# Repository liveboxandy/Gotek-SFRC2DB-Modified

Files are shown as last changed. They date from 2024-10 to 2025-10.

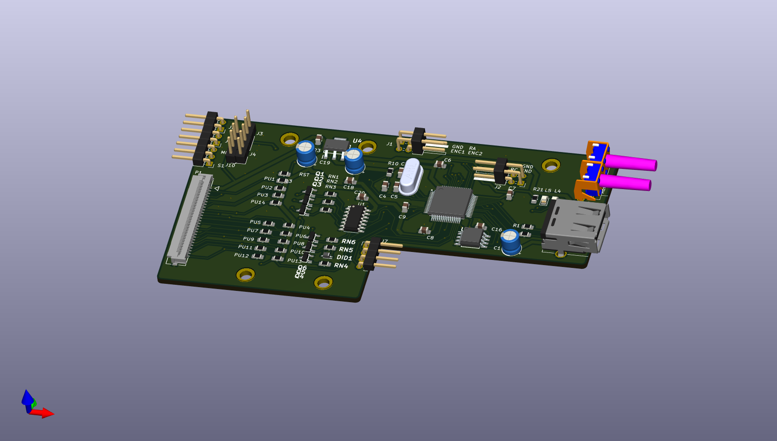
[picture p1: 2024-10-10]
Gotek.png

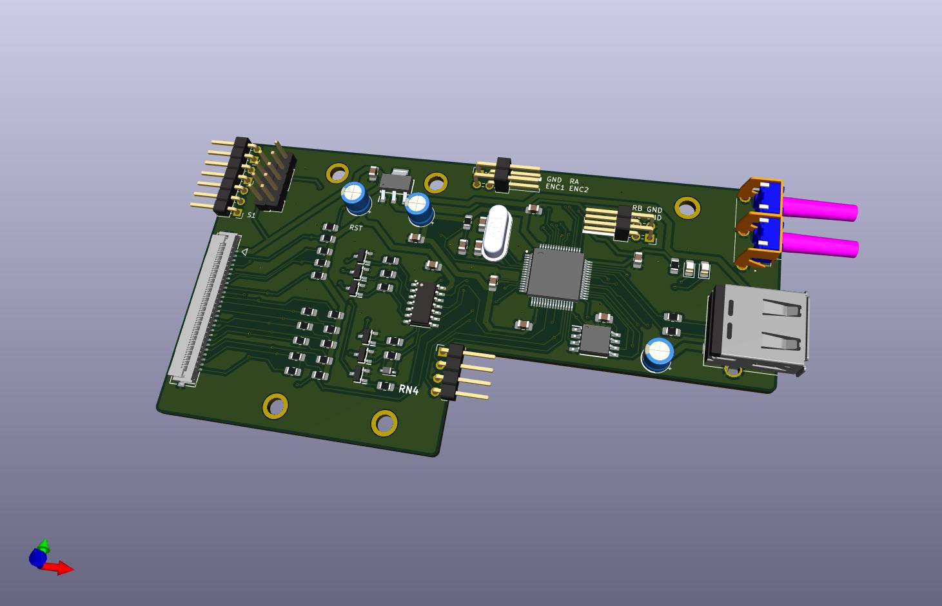
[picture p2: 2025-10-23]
Gotek.jpg

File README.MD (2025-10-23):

Initial schematic and gerbers for a Gotek SFRC2D.B based on an Artery St32F415 chip.
Used photographs and a multimeter without removing any chips. Only removed RA/RB/RC to verify connections to U3.
Should work for the STM105 variant as some of the smoothing caps don't make sense for the Artery chip but do for the STM.
Added connections for a rotary encoder (J1) using U3 Pins 50 (PC10), 51 (PC11) and 37 (PC6) and replaced RB and RC with
a 2x2 RA pin header (J2).

Updated for Kicad 9
Added ibom (bom/ibom.html)
Restructered Folders

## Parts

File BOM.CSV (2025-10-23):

Reference | Value | Datasheet | Footprint | Qty | DNP
C1,C17,C19 | 10uF | ~ | Capacitor_THT:CP_Radial_D5.0mm_P2.50mm | 3
C3,C5 | 22pF | ~ | Capacitor_SMD:C_0805_2012Metric_Pad1.18x1.45mm_HandSolder | 2
C4,C6,C7,C8,C9,C16,C18,C20,C23 | 100nF | ~ | Capacitor_SMD:C_0805_2012Metric_Pad1.18x1.45mm_HandSolder | 9
DID1 | 1N4148WS | https://www.vishay.com/docs/85751/1n4148ws.pdf | Gotek:SODFL2512X90N | 1
J1,J2 | Conn_02x02_Odd_Even | ~ | Connector_PinHeader_2.54mm:PinHeader_2x02_P2.54mm_Horizontal | 2
J3,MO1 | Conn_01x03_Pin | ~ | Connector_PinHeader_2.54mm:PinHeader_1x03_P2.54mm_Horizontal,Connector_PinHeader_2.54mm:PinHeader_1x03_P2.54mm_Vertical | 2
J4,JD1,JE1 | Conn_01x02_Pin | ~ | Connector_PinHeader_2.54mm:PinHeader_1x02_P2.54mm_Horizontal,Connector_PinHeader_2.54mm:PinHeader_1x02_P2.54mm_Vertical | 3
J7 | Display Port | ~ | Connector_PinHeader_2.54mm:PinHeader_1x04_P2.54mm_Horizontal | 1
J10 | Conn_01x04_Pin | ~ | Connector_PinHeader_2.54mm:PinHeader_1x04_P2.54mm_Vertical | 1
L4 | LED GREEN | ~ | LED_SMD:LED_0805_2012Metric_Pad1.15x1.40mm_HandSolder | 1
L5 | LED RED | ~ | LED_SMD:LED_0805_2012Metric_Pad1.15x1.40mm_HandSolder | 1
P1 | Conn_01x26 | 2005280260 | Gotek:MOLEX_CON_2005280260 | 1
P3 | USB_A | ~ | Connector_USB:USB_A_Molex_67643_Horizontal | 1
PU1,PU2,PU3,PU4,PU5,PU6,PU7,PU8,PU9,PU10,PU11,PU12,PU13,PU14,R21,RN1,RN2,RN3,RN4,RN5,RN6 | 1K | ~ | Resistor_SMD:R_0805_2012Metric_Pad1.20x1.40mm_HandSolder | 21
Q1,Q2,Q3,Q4,Q5,Q6 | PMBT2222A,215 | https://assets.nexperia.com/documents/data-sheet/PMBT2222A.pdf | Gotek:SOT95P280X130-3N | 6
R1,R2 | 22R | ~ | Resistor_SMD:R_0805_2012Metric_Pad1.20x1.40mm_HandSolder | 2
R10,RN13 | 4K7 | ~ | Resistor_SMD:R_0805_2012Metric_Pad1.20x1.40mm_HandSolder | 2
S3,S4 | SKHHANA010 | https://www.mouser.co.uk/datasheet/2/15/SKHH-1370651.pdf | Gotek:SKHHLQA010 | 2
U1 | 74AHC04 | https://assets.nexperia.com/documents/data-sheet/74AHC_AHCT04.pdf | Package_SO:SO-14_3.9x8.65mm_P1.27mm | 1
U3 | at32f415rbt7 | https://www.arterytek.com/download/DS/DS_AT32F415_V2.01_CH.pdf | Gotek:QFP50P1200X1200X160-64N | 1
U4 | AMS1117-3.3 | http://www.advanced-monolithic.com/pdf/ds1117.pdf | Gotek:SOT229P700X180-4N | 1
U8 | SST25VF016B-50-4C-S2AF | https://ww1.microchip.com/downloads/en/DeviceDoc/20005044C.pdf | Gotek:SOIC127P790X216-8N | 1
Y1 | 8Mhz | ~ | Crystal:Crystal_HC18-U_Vertical | 1

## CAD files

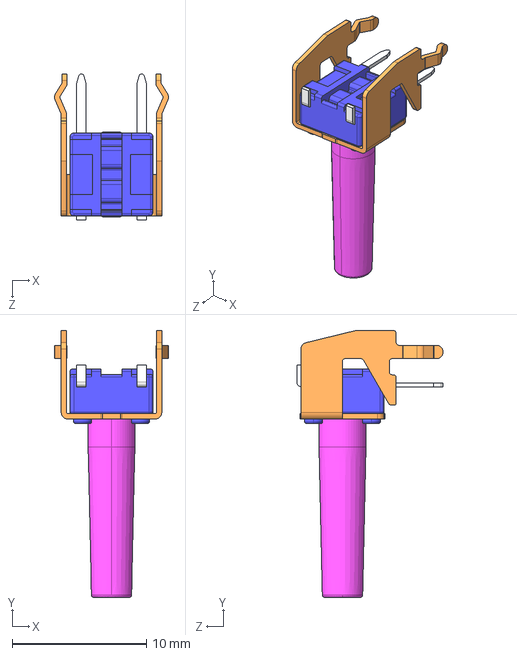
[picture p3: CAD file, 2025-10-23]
STP/SKHHNH.stp
8.50 x 19.9 x 10.9 mm

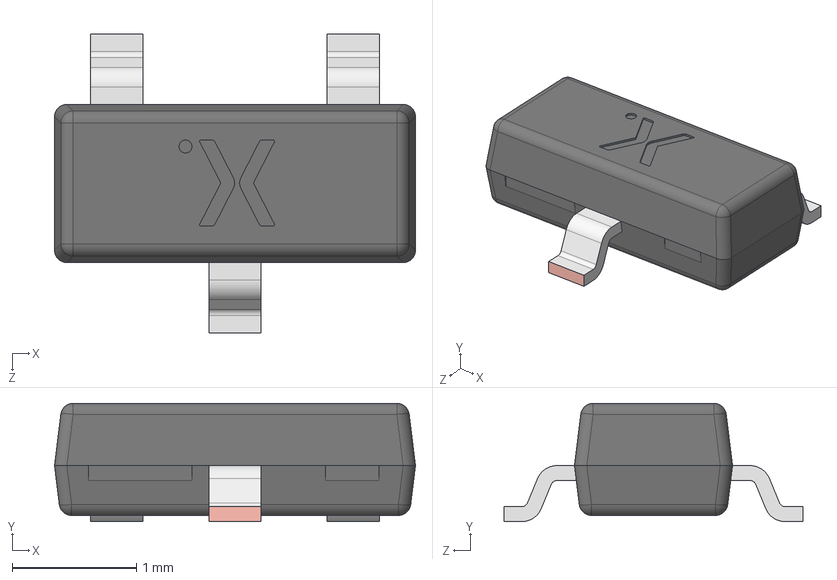
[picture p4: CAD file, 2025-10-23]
STP/PMBT2222A,215.stp
2.90 x 0.95 x 2.40 mm
SOT23 lower body
SOT23 Lead x 3
SOT23 Upper body

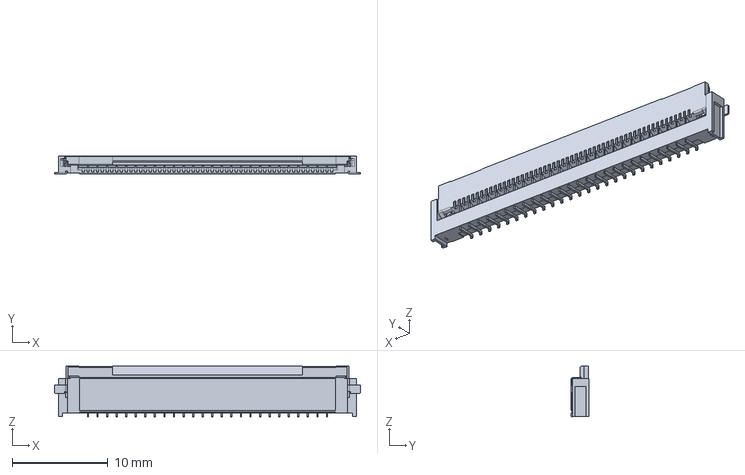
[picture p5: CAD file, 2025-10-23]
STP/Molex 2005280260.stp
32.0 x 1.90 x 5.30 mm

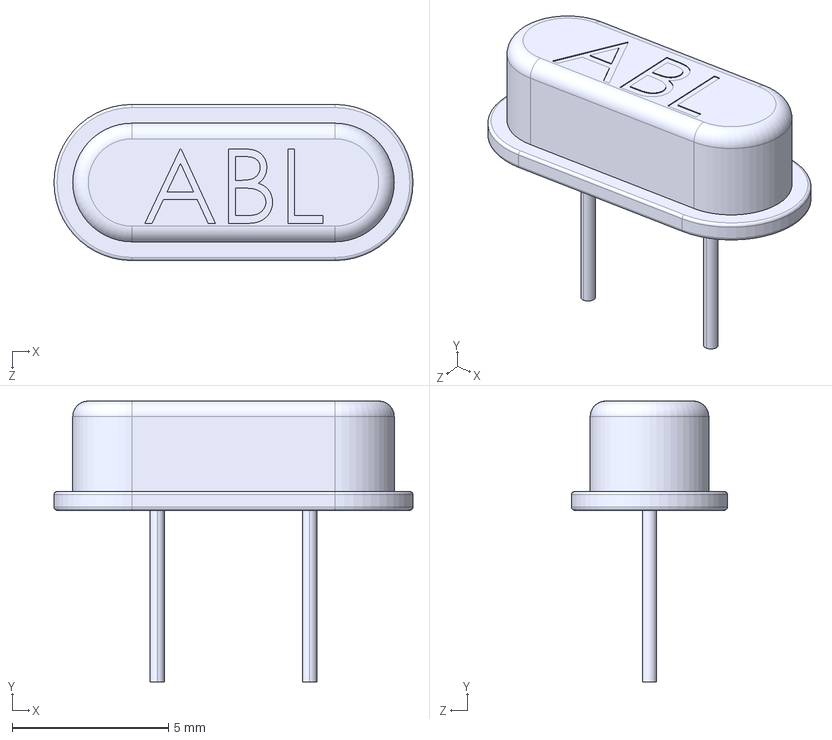
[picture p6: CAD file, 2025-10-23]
STP/ABL-8.000MHZ-B2.stp
11.5 x 9.00 x 5.00 mm

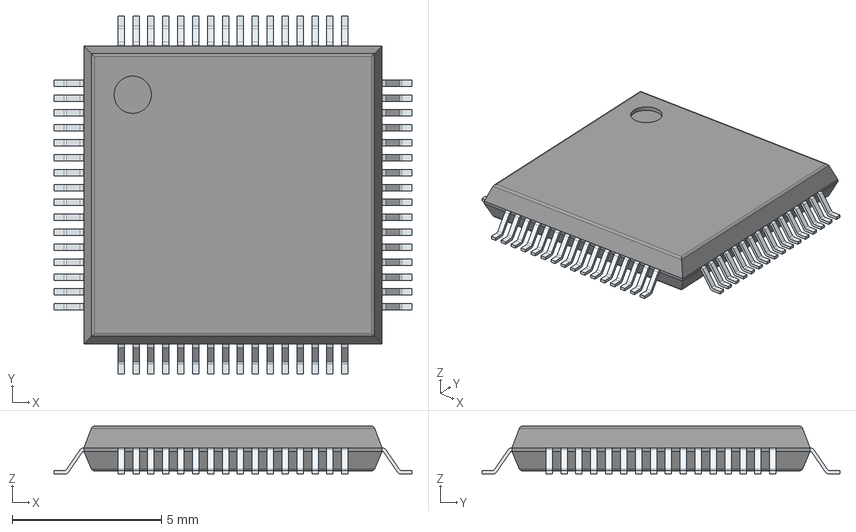
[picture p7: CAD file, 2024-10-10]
STP/AT32F415RxT7.stp
12.0 x 12.0 x 1.60 mm
PinsArrayLR
PinsArrayTB

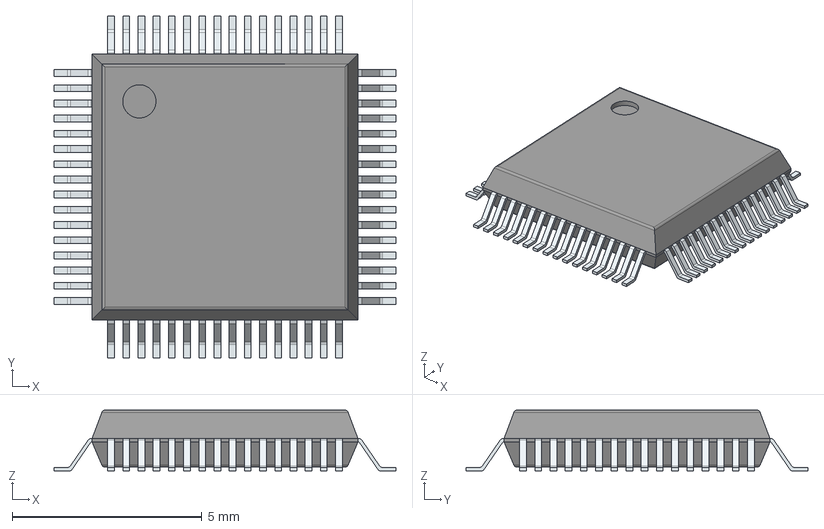
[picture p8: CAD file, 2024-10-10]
STP/at32f415rct7.stp
9.00 x 9.00 x 1.60 mm
PinsArrayLR
PinsArrayTB

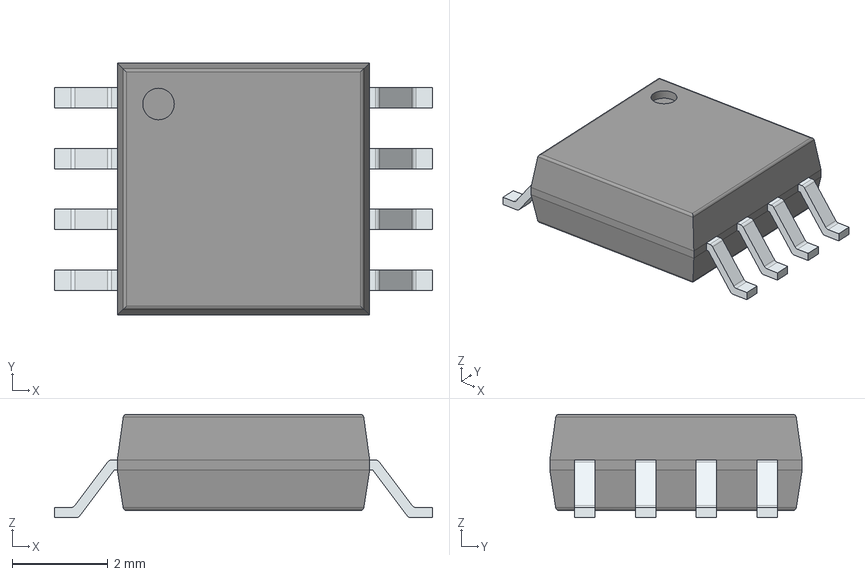
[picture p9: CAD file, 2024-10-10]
STP/SST25VF016B-50-4C-S2AF.stp
7.90 x 5.28 x 2.16 mm
PinsArrayLR

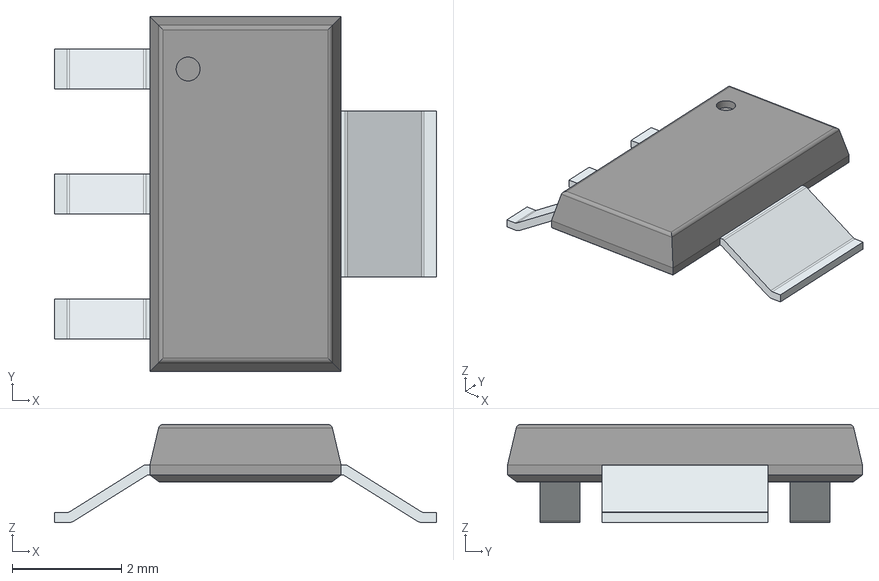
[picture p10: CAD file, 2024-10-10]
STP/ams1117-3.3v.stp
7.00 x 6.50 x 1.80 mm
PinsArrayL
FilletPinR

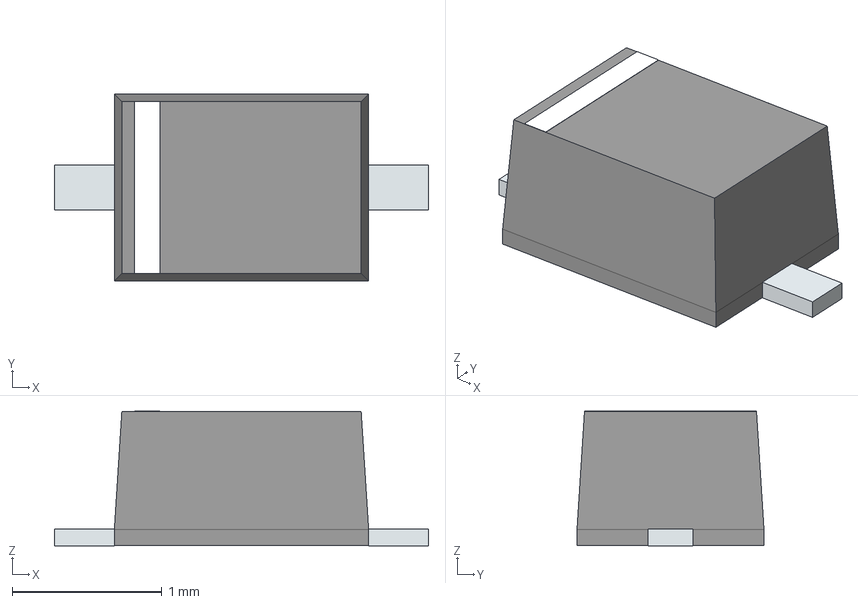
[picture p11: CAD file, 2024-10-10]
STP/1N4148WS.stp
2.50 x 1.25 x 0.9 mm
PinKIdent
PinK
PinA

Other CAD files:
STP/SKHHNK.STEP
STP/SKHHNHA010.stp
STP/SKHHNK.stp

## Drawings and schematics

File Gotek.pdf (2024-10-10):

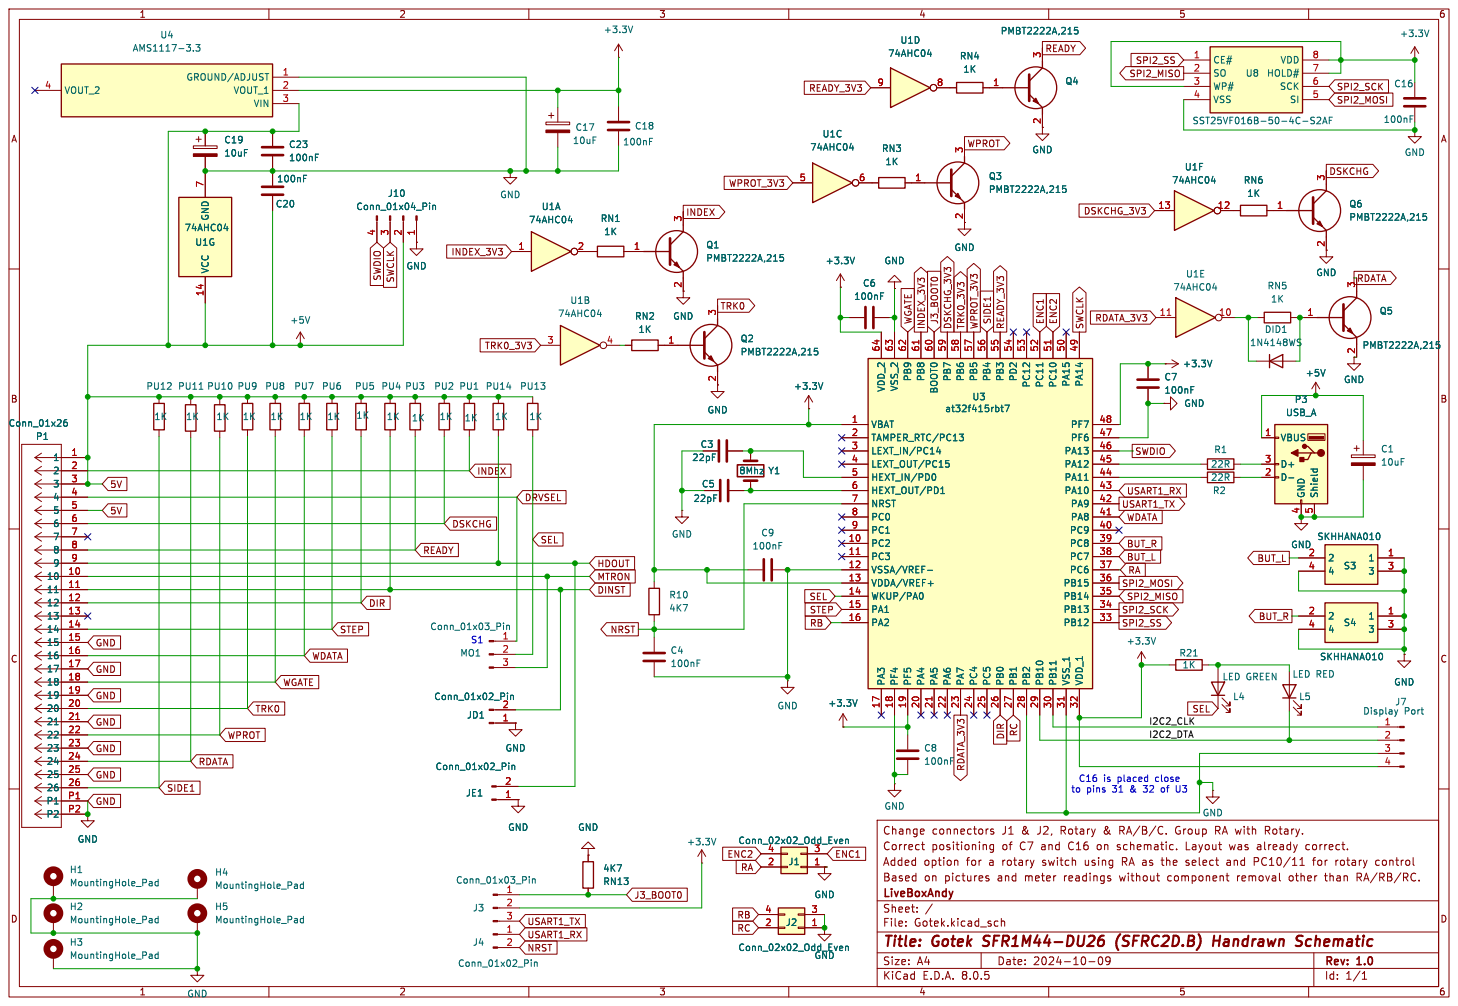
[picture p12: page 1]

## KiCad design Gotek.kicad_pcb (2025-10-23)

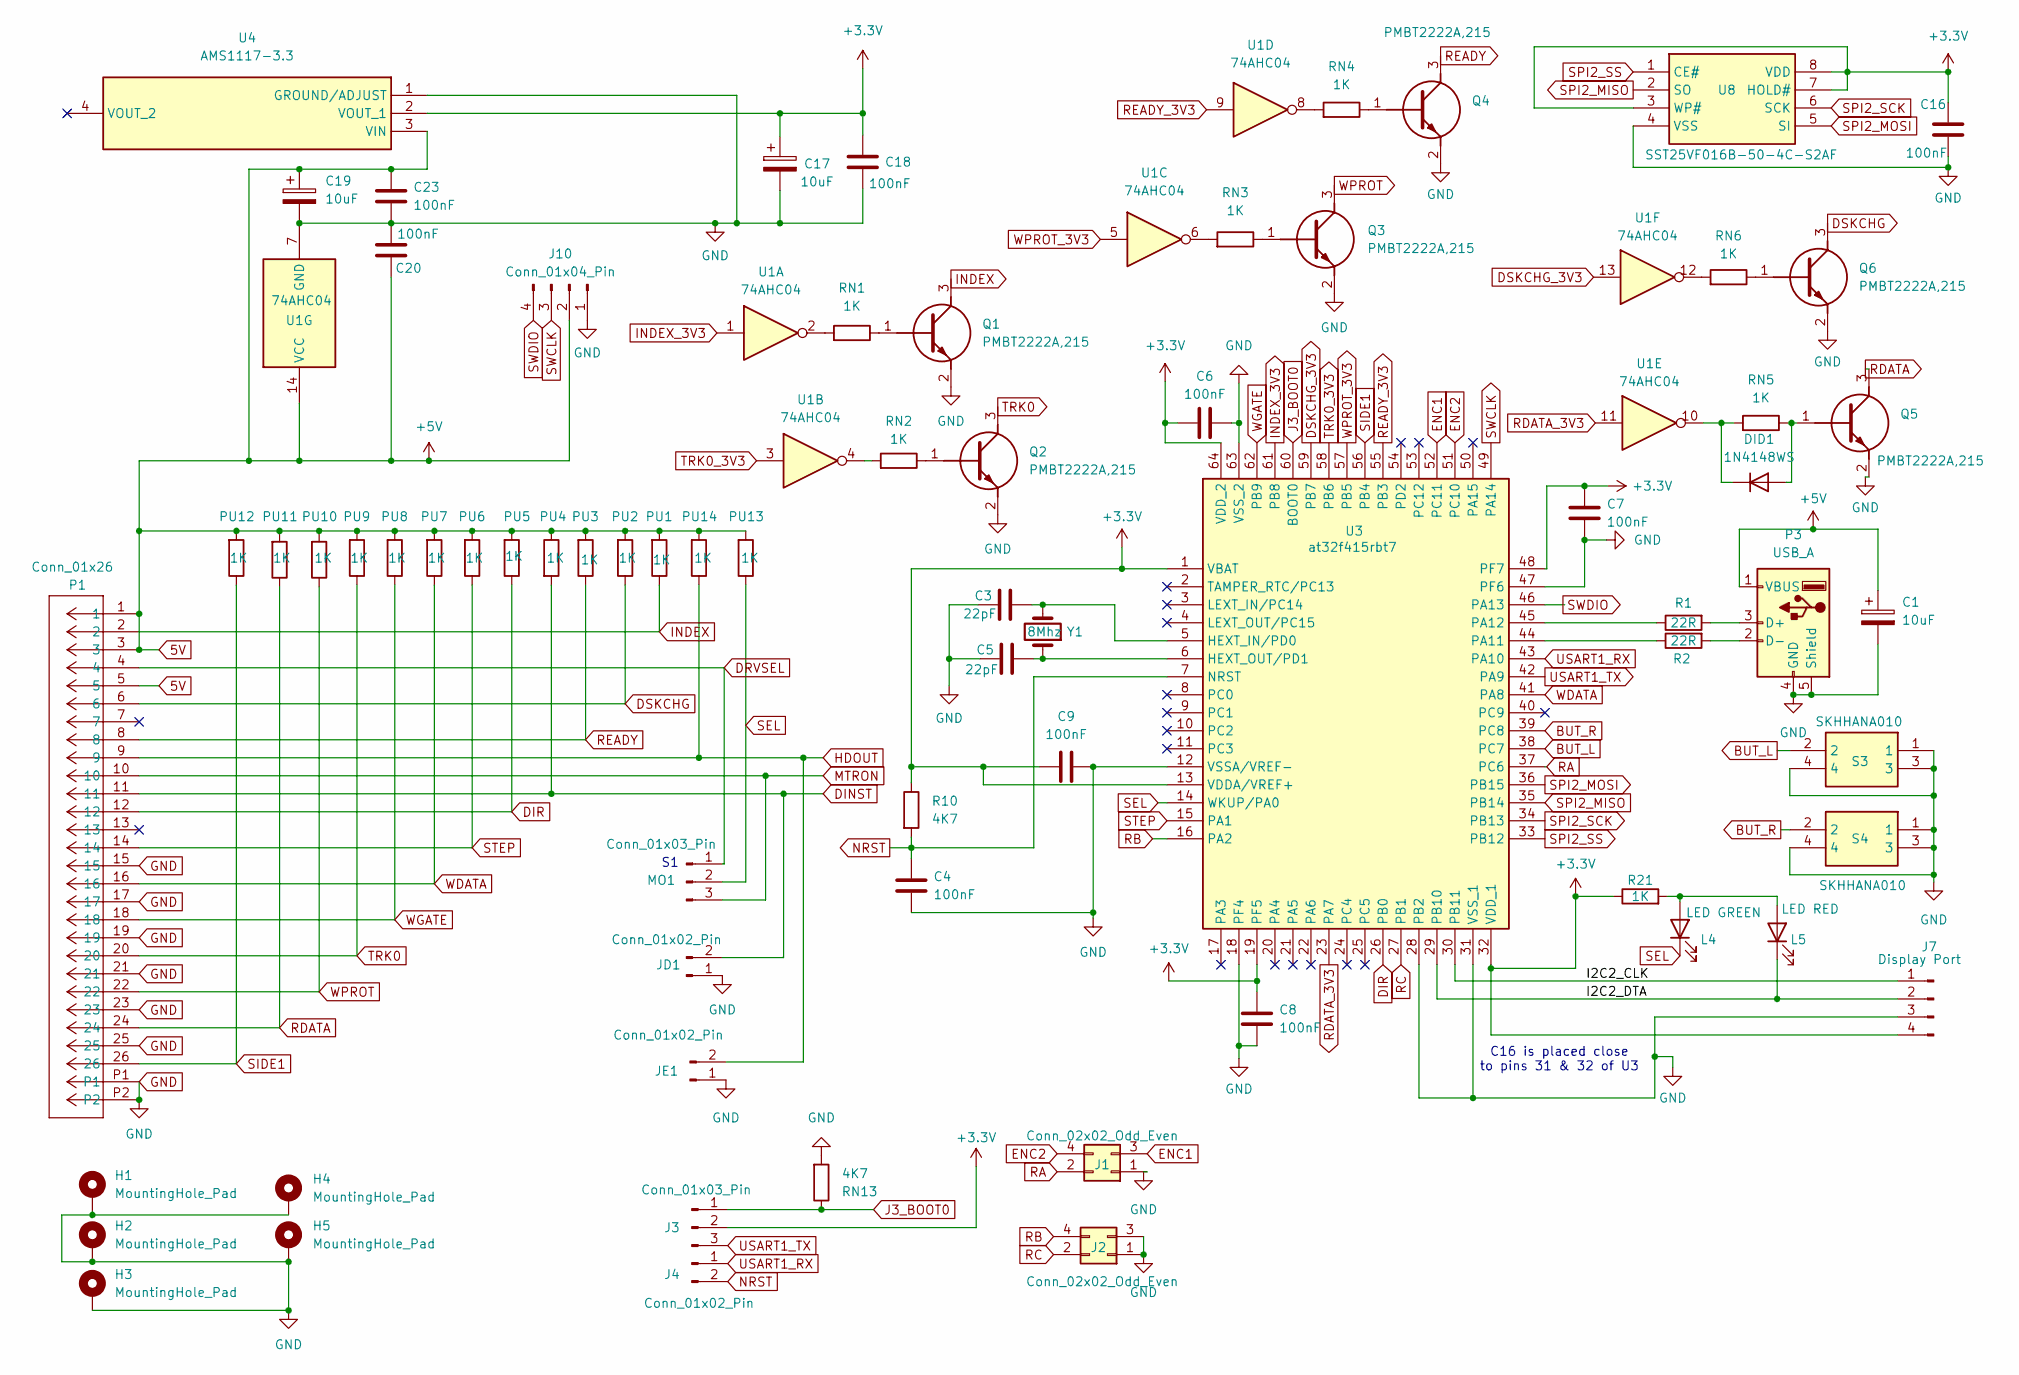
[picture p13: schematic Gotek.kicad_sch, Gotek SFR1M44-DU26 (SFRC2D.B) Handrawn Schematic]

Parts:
C1, C17, C19: 10uF; CP_Radial_D5.0mm_P2.50mm
C3, C5: 22pF; C_0805_2012Metric_Pad1.18x1.45mm_HandSolder
C4, C6, C7, C8, C9, C16, C18, C20, C23: 100nF; C_0805_2012Metric_Pad1.18x1.45mm_HandSolder
DID1: 1N4148WS; SODFL2512X90N
H1, H2, H3, H4, H5: MountingHole_Pad; MountingHole_M3_Pad
J1, J2: Conn_02x02_Odd_Even; PinHeader_2x02_P2.54mm_Horizontal
J3: Conn_01x03_Pin; PinHeader_1x03_P2.54mm_Vertical
J4: Conn_01x02_Pin; PinHeader_1x02_P2.54mm_Vertical
J7: Display Port; PinHeader_1x04_P2.54mm_Horizontal
J10: Conn_01x04_Pin; PinHeader_1x04_P2.54mm_Vertical
JD1: Conn_01x02_Pin; PinHeader_1x02_P2.54mm_Horizontal
JE1: Conn_01x02_Pin; PinHeader_1x02_P2.54mm_Horizontal
L4: LED GREEN; LED_0805_2012Metric_Pad1.15x1.40mm_HandSolder
L5: LED RED; LED_0805_2012Metric_Pad1.15x1.40mm_HandSolder
MO1: Conn_01x03_Pin; PinHeader_1x03_P2.54mm_Horizontal
P1: Conn_01x26; MOLEX_CON_2005280260
P3: USB_A; USB_A_Molex_67643_Horizontal
PU1, PU2, PU3, PU4, PU5, PU6, PU7, PU8, PU9, PU10, PU11, PU12, PU13, PU14: 1K; R_0805_2012Metric_Pad1.20x1.40mm_HandSolder
Q1, Q2, Q3, Q4, Q5, Q6: PMBT2222A,215; SOT95P280X130-3N; Mouser Part Number 771-PMBT2222A-T/R
R1, R2: 22R; R_0805_2012Metric_Pad1.20x1.40mm_HandSolder
R10: 4K7; R_0805_2012Metric_Pad1.20x1.40mm_HandSolder
R21: 1K; R_0805_2012Metric_Pad1.20x1.40mm_HandSolder
RN1, RN2, RN3, RN4, RN5, RN6: 1K; R_0805_2012Metric_Pad1.20x1.40mm_HandSolder
RN13: 4K7; R_0805_2012Metric_Pad1.20x1.40mm_HandSolder
S3, S4: SKHHANA010; SKHHLQA010; Mouser Part Number 688-SKHHAN
U1: 74AHC04; SO-14_3.9x8.65mm_P1.27mm
U3: at32f415rbt7; QFP50P1200X1200X160-64N; Manufacturer_Part_Number at32f415rct7
U4: AMS1117-3.3; SOT229P700X180-4N; Manufacturer_Part_Number ams1117-3.3v
U8: SST25VF016B-50-4C-S2AF; SOIC127P790X216-8N; Mouser Part Number 579-25VF016B504CS2AF
Y1: 8Mhz; Crystal_HC18-U_Vertical

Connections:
5V: C1.1, C19.1, C20.2, C23.1, J10.2, P1.1, P1.3, P1.5, P3.1 (VBUS), PU1.2, PU2.2, PU3.2, PU4.1, PU5.2, PU6.2, PU7.2, PU8.2, PU9.2, PU10.2, PU11.2, PU12.2, PU13.2, PU14.2, U1.14 (VCC), U4.3 (VIN)
+3.3V: C6.1, C7.1, C8.1, C9.2, C16.2, C17.1, C18.2, J3.2, J7.4, R10.1, R21.1, U3.1 (VBAT), U3.13 (VDDA/VREF+), U3.19 (PF5), U3.32 (VDD_1), U3.48 (PF7), U3.64 (VDD_2), U4.2 (VOUT_1), U8.3 (WP#), U8.7 (HOLD#), U8.8 (VDD)
/I2C2_CLK: J7.1, U3.30 (PB11)
/I2C2_DTA: J7.2, L5.1 (K), U3.29 (PB10)
BUT_L: S3.2, U3.38 (PC7)
BUT_R: S4.2, U3.39 (PC8)
DINST: JD1.2, P1.11, PU4.2
DIR: P1.12, PU5.1, U3.26 (PB0)
DRVSEL: MO1.1, P1.4
DSKCHG: P1.6, PU2.1, Q6.3 (C)
DSKCHG_3V3: U1.13, U3.59 (PB7)
ENC1: J1.3, U3.52 (PC11)
ENC2: J1.4, U3.51 (PC10)
GND: C1.2, C3.1, C4.2, C5.2, C6.2, C7.2, C8.2, C9.1, C16.1, C17.2, C18.1, C19.2, C20.1, C23.2, H1.1, H2.1, H3.1, H4.1, H5.1, J1.1, J2.1, J2.3, J7.3, J10.1, JD1.1, JE1.1, P1.15, P1.17, P1.19, P1.21, P1.23, P1.25, P1.P1, P1.P2, P3.4 (GND), P3.5 (Shield), Q1.2 (E), Q2.2 (E), Q3.2 (E), Q4.2 (E), Q5.2 (E), Q6.2 (E), RN13.2, S3.1, S3.3, S3.4, S4.1, S4.3, S4.4, U1.7 (GND), U3.12 (VSSA/VREF-), U3.18 (PF4), U3.28 (PB2), U3.31 (VSS_1), U3.47 (PF6), U3.63 (VSS_2), U4.1 (GROUND/ADJUST), U8.4 (VSS)
HDOUT: JE1.2, P1.9, PU14.1
INDEX: P1.2, PU1.1, Q1.3 (C)
INDEX_3V3: U1.1, U3.61 (PB8)
J3_BOOT0: J3.1, RN13.1, U3.60 (BOOT0)
MTRON: MO1.3, P1.10
NRST: C4.1, J4.2, R10.2, U3.7 (NRST)
unnamed: DID1.2 (A), Q5.1 (B), RN5.1
unnamed: DID1.1 (K), RN5.2, U1.10
unnamed: L4.2 (A), L5.2 (A), R21.2
unnamed: P3.3 (D+), R1.2
unnamed: P3.2 (D-), R2.2
unnamed: Q1.1 (B), RN1.1
unnamed: Q2.1 (B), RN2.1
unnamed: Q3.1 (B), RN3.1
unnamed: Q4.1 (B), RN4.1
unnamed: Q6.1 (B), RN6.1
unnamed: RN1.2, U1.2
unnamed: RN2.2, U1.4
unnamed: RN3.2, U1.6
unnamed: RN4.2, U1.8
unnamed: RN6.2, U1.12
unnamed: C3.2, U3.5 (HEXT_IN/PD0), Y1.2
unnamed: C5.1, U3.6 (HEXT_OUT/PD1), Y1.1
unnamed: R2.1, U3.44 (PA11)
unnamed: R1.1, U3.45 (PA12)
RA: J1.2, U3.37 (PC6)
RB: J2.4, U3.16 (PA2)
RC: J2.2, U3.27 (PB1)
RDATA: P1.24, PU11.1, Q5.3 (C)
RDATA_3V3: U1.11, U3.23 (PA7)
READY: P1.8, PU3.1, Q4.3 (C)
READY_3V3: U1.9, U3.55 (PB3)
SEL: L4.1 (K), MO1.2, PU13.1, U3.14 (WKUP/PA0)
SIDE1: P1.26, PU12.1, U3.56 (PB4)
SPI2_MISO: U3.35 (PB14), U8.2 (SO)
SPI2_MOSI: U3.36 (PB15), U8.5 (SI)
SPI2_SCK: U3.34 (PB13), U8.6 (SCK)
SPI2_SS: U3.33 (PB12), U8.1 (CE#)
STEP: P1.14, PU6.1, U3.15 (PA1)
SWCLK: J10.3, U3.49 (PA14)
SWDIO: J10.4, U3.46 (PA13)
TRK0: P1.20, PU9.1, Q2.3 (C)
TRK0_3V3: U1.3, U3.58 (PB6)
USART1_RX: J4.1, U3.43 (PA10)
USART1_TX: J3.3, U3.42 (PA9)
WDATA: P1.16, PU7.1, U3.41 (PA8)
WGATE: P1.18, PU8.1, U3.62 (PB9)
WPROT: P1.22, PU10.1, Q3.3 (C)
WPROT_3V3: U1.5, U3.57 (PB5)

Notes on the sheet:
C16 is placed close to pins 31 & 32 of U3

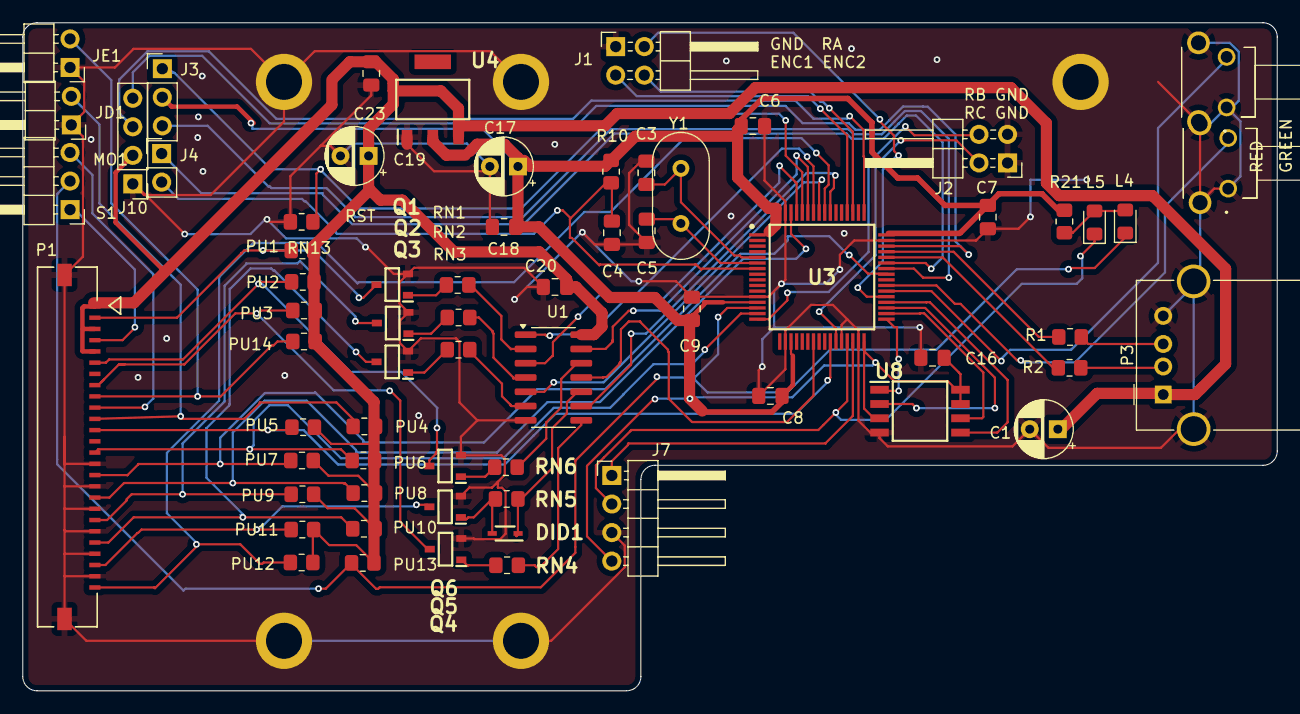
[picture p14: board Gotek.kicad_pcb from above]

Board: 2 copper layers, 111.6 x 59.4 mm, 71 parts (0 on the bottom side), 63 nets.

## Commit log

2024-10-10 Add files via upload
    Initial upload
    [1N4148WS.stp, ABL-8.000MHZ-B2.stp, AT32F415RxT7.stp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]
2025-10-23 Added ibom and minor changes
    Update for Kicad 9
    Added ibom (bom/ibom.html)
    Restructured folders.
    [1N4148WS.stp, ABL-8.000MHZ-B2.stp, AT32F415RxT7.stp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]
